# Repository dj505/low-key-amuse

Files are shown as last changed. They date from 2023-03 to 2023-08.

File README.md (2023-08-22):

# low-key-amuse
A low-key e-amusement keypad for DDR cabs (and other cabs? :eyes:)  
low-key-amuse  
(Dimensions may vary with revisions!)

# Bill of Materials
| Part | Qty | Description |
|---|-----|---|
|MPR121 |1 |Touch sensor |
|16 pin FFC |1 |Reverse direction, 1mm pitch |
|100nF capacitor |2 |SMD, 0805 package |
|75k ohm resistor |1 |SMD, 0805 package |
|4.2k ohm resistor |2 |SMD, 0805 package |
|Raspberry Pi Pico |1 | |
|TE Connectivity 1-84952-6 |2 |FPC connector, 16 pin, bottom contacts |

**Notes:**
* Be sure the ribbon cables you purchase match the connectors. "Forward" direction ribbons will require you to use connectors with top contacts, however I would recommend "reverse" direction ribbons with bottom contact connectors.
* Some PCBA services might not carry 4.2k ohm resistors, or they may be difficult to find. Anything from 2k to 10k ohms should work. This is just what worked for me personally in testing.

# Required Libraries
All of the required libraries can be found in the [library bundle] for your installed version of CircuitPython. This project was built and tested with 8.x.x. The following should be placed in the `lib` folder on the `CIRCUITPY` drive:
* adafruit_bus_device
* adafruit_hid
* adafruit_mpr121.mpy

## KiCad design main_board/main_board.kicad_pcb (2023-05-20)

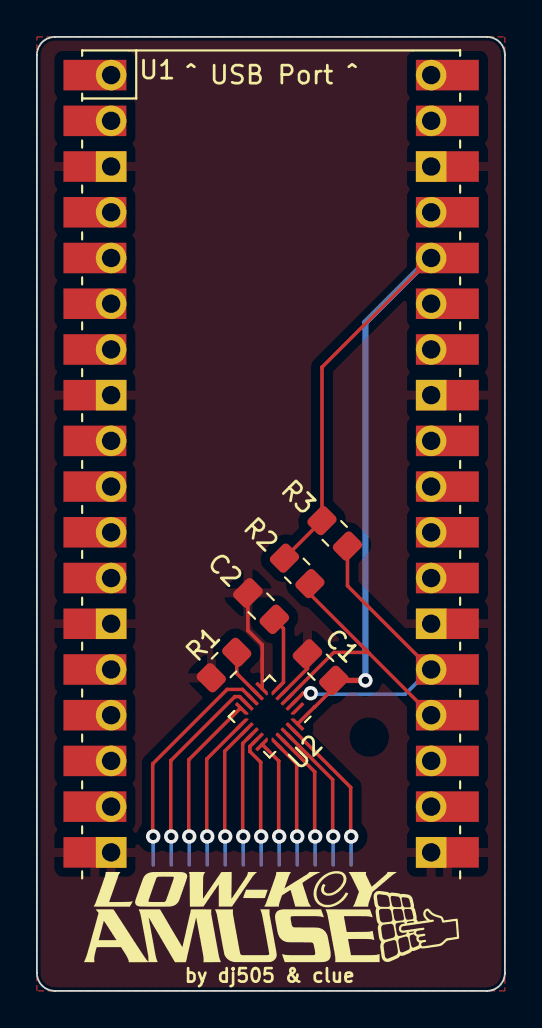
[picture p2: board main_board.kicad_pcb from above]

Board: 2 copper layers, 26.0 x 53.0 mm, 8 parts (1 on the bottom side), 18 nets.

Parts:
C1, C2: 100nF; C_0805_2012Metric_Pad1.18x1.45mm_HandSolder
J1: Conn_01x16; TE_1-84952-6_1x16-1MP_P1.0mm_Horizontal
R1: 75k; R_0805_2012Metric_Pad1.20x1.40mm_HandSolder
R2, R3: 4.2k; R_0805_2012Metric_Pad1.20x1.40mm_HandSolder
U1: Pico; RPi_Pico_SMD_TH
U2: MPR121QR2; UQFN-20_3x3mm_P0.4mm

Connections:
+3V3: C1.2, R2.2, R3.2, U1.36 (3V3), U2.20 (VDD)
GND: C1.1, C2.1, J1.1, J1.16, R1.1, U1.3 (GND), U1.8 (GND), U1.13 (GND), U1.18 (GND), U1.23 (GND), U1.28 (GND), U1.33 (AGND), U1.38 (GND), U2.4 (ADDR), U2.6 (VSS)
unnamed: R1.2, U2.7 (REXT)
unnamed: C2.2, U2.5 (VREG)
PAD0: J1.15, U2.8 (ELE0)
PAD1: J1.14, U2.9 (ELE1)
PAD2: J1.13, U2.10 (ELE2)
PAD3: J1.12, U2.11 (ELE3)
PAD4: J1.11, U2.12 (LED0/ELE4)
PAD5: J1.10, U2.13 (LED1/ELE5)
PAD6: J1.9, U2.14 (LED2/ELE6)
PAD7: J1.8, U2.15 (LED3/ELE7)
PAD8: J1.7, U2.16 (LED4/ELE8)
PAD9: J1.6, U2.17 (LED5/ELE9)
PAD10: J1.5, U2.18 (LED6/ELE10)
PAD11: J1.4, U2.19 (LED7/ELE11)
SCL: R3.1, U1.27 (GPIO21), U2.2 (SCL)
SDA: R2.1, U1.26 (GPIO20), U2.3 (SDA)

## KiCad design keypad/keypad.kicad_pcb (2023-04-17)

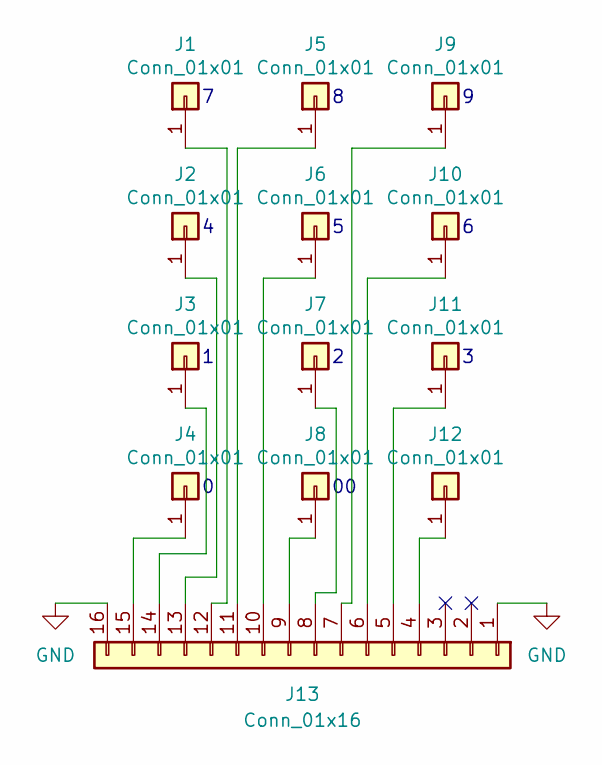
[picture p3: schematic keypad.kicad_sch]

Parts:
J1, J2, J3, J4, J5, J6, J7, J8, J9, J10, J11, J12: Conn_01x01
J13: Conn_01x16; TE_1-84952-6_1x16-1MP_P1.0mm_Horizontal

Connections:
GND: J13.1, J13.16
unnamed: J1.1, J13.12
unnamed: J10.1, J13.6
unnamed: J11.1, J13.5
unnamed: J12.1, J13.4
unnamed: J9.1, J13.7
unnamed: J7.1, J13.8
unnamed: J8.1, J13.9
unnamed: J6.1, J13.10
unnamed: J5.1, J13.11
unnamed: J2.1, J13.13
unnamed: J3.1, J13.14
unnamed: J4.1, J13.15

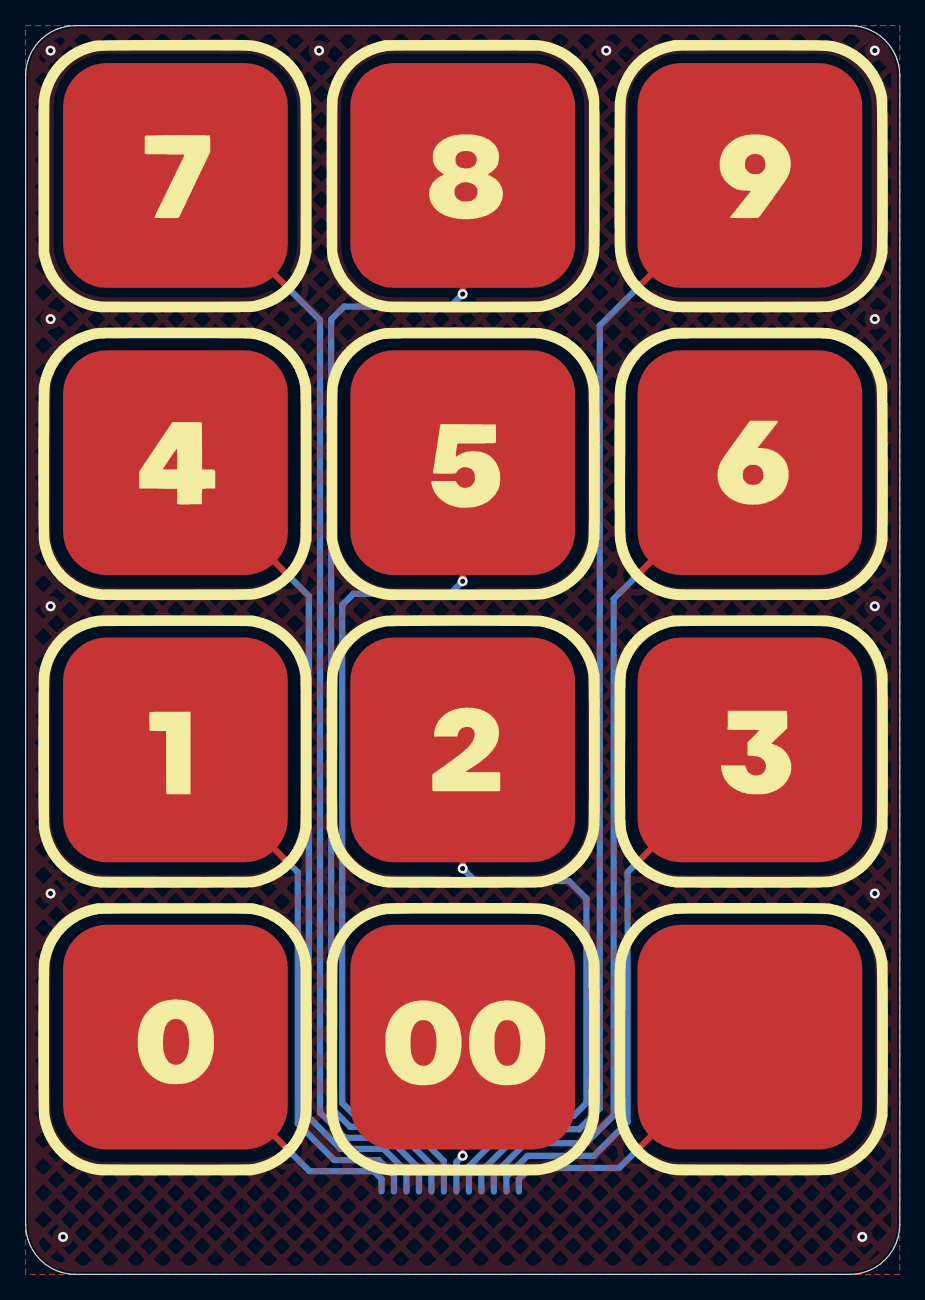
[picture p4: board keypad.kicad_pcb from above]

Board: 2 copper layers, 70.0 x 100.0 mm, 13 parts (1 on the bottom side), 13 nets.

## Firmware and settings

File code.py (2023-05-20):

import time
import board
import busio
import adafruit_mpr121
import digitalio
import usb_hid
from adafruit_hid.keyboard import Keyboard
from adafruit_hid.keyboard_layout_us import KeyboardLayoutUS
from adafruit_hid.keycode import Keycode

i2c = busio.I2C(board.GP21, board.GP20)
mpr121 = adafruit_mpr121.MPR121(i2c)
led = digitalio.DigitalInOut(board.LED)
led.direction = digitalio.Direction.OUTPUT

# Config
player_side = 1

# Pin mappings correspond to keypad keys from left to right, top to bottom.
# Most of the keycodes you'll need can be found at:
# https://docs.circuitpython.org/projects/hid/en/latest/_modules/adafruit_hid/keycode.html
pin_mapping_p1 = {
    3:  Keycode.KEYPAD_SEVEN,
    4:  Keycode.KEYPAD_EIGHT,
    8:  Keycode.KEYPAD_NINE,
    2:  Keycode.KEYPAD_FOUR,
    5:  Keycode.KEYPAD_FIVE,
    9:  Keycode.KEYPAD_SIX,
    1:  Keycode.KEYPAD_ONE,
    7:  Keycode.KEYPAD_TWO,
    10: Keycode.KEYPAD_THREE,
    0:  Keycode.KEYPAD_ZERO,
    6:  Keycode.KEYPAD_ENTER,
    11: Keycode.KEYPAD_PERIOD,
}

pin_mapping_p2 = {
    3:  Keycode.I,
    4:  Keycode.O,
    8:  Keycode.P,
    2:  Keycode.J,
    5:  Keycode.K,
    9:  Keycode.L,
    1:  Keycode.B,
    7:  Keycode.N,
    10: Keycode.M,
    0:  Keycode.COMMA,
    6:  Keycode.PERIOD,
    11: Keycode.FORWARD_SLASH,
}

key_map = pin_mapping_p1

if player_side == 2:
    key_map = pin_mapping_p2

keyboard = Keyboard(usb_hid.devices)
keyboard_layout = KeyboardLayoutUS(keyboard)

while True:
    for i in range(12):
        if mpr121[i].value:
            keyboard.press(key_map[i])
            led.value = True
        else:
            keyboard.release(key_map[i])
            led.value = False

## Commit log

2023-02-16 First keypad design, initial footprints
    [keypad.kicad_pcb, keypad.kicad_sch]
2023-02-16 Create main board project, USB schematic
    [main_board.kicad_pcb, main_board.kicad_sch]
2023-02-17 Main board schematic updates
    [keypad.kicad_pcb, keypad.kicad_sch, main_board.kicad_sch]
2023-02-17 done RP2040 routing, near final component layout
    [main_board.kicad_pcb, main_board.kicad_sch]
2023-03-01 keypad rev 1 done + gerber
    [keypad-B_Cu.gbl, keypad-B_Mask.gbs, keypad-B_Paste.gbp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]
2023-03-16 move to MPR121
    [main_board.kicad_sch]
2023-03-22 Main board complete?
    [main_board.kicad_pcb, main_board.kicad_sch]
2023-03-22 oops forgot to ctrl+S
    [main_board.kicad_pcb]
2023-03-28 Alignment fixes, generate gerbers
    [keypad-B_Cu.gbl, keypad-B_Mask.gbs, keypad-B_Paste.gbp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]
2023-03-28 Add tooling holes, update logo, other adjustments
    [keypad.kicad_pcb, main_board.kicad_pcb, main_board.kicad_sch]
2023-03-28 didn't actually update gerbers last time oops
2023-03-28 Fic DRC errors
    [main_board.kicad_pcb, main_board.kicad_sch]
2023-03-28 remove sneaky REF*** text
    [main_board.kicad_pcb]
2023-03-28 update files to match first prototype run
2023-04-17 Update keypad with ffc connector
    [keypad.kicad_pcb, keypad.kicad_sch]
2023-05-20 Add code.py, update gerbers/prod files
    [main_board.kicad_pcb, main_board.kicad_sch]
